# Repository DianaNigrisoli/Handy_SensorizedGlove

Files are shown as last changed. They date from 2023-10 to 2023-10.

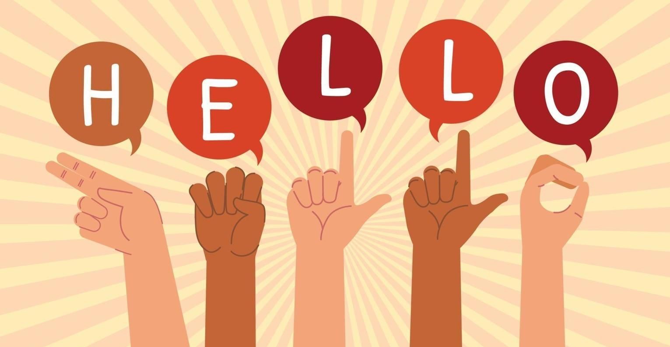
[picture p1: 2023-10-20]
Software/01_Graphics/Download Hello Hand Sign Language Concept for free.jpeg

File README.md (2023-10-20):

# Handy_SensorizedGlove
A wireless sensorized glove for ASL fingerspelling gesture recognition. 
### Course
Electronic Technologies and Biosensor Laboratories

### Developers 
- Arianna De Vecchi <br> arianna.devecchi@mail.polimi.it
- Ilaria Crupi <br> ilaria.crupi@mail.polimi.it
- Diana Nigrisoli <br> diana.nigrisoli@mail.polimi.it

### Setup
* In the command prompt execute:
    ```console
    git clone https://github.com/DianaNigrisoli/Handy_SensorizedGlove.git
    
### Development 
You can find all the scripts and designs in the following folders: 
* Hardware: EAGLE design of the PCB
* Firmware: PSoC Creator code
* Software: Python software for GUI development and Machine Learning classification 
* Box_Solidworks: SOLIDWORKS Part Document of the 3D printed box

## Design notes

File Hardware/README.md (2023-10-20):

# Hardware

## Contents 
In "Project_04" folder: 

| File | Description |
|---|---|
| `Project_04_Schematic.sch` | Schematic |
| `Project_04_Board.brd` | Board |
| `Project_04_ToPrint.pdf` | PCB Design PDF file 1:1 scaled |
| `sparkfun.dru` | Design rules | 
| `README.md` | This README file. |

## Tools 

Both Schematic and Board Design were implemented using the 9.6.2 version of EAGLE software. 

## Detailed files description 
### Schematic 
#### List of schematic components 
| Name | Description | On PCB |
| --- | --- | --- |
| J1 | Plated through-hole 7 pin connector | Generic 0.1 inch spaced male headers connected to flex sensors and force-sensing resistors |
| J2 | Plated through-hole 7 pin connector | Generic 0.1 inch spaced male headers connected to 3.3V supply voltage | 
| J3.1 - PSOC | Plated through-hole 7 pin connector | Generic 0.1 inch spaced female headers connected to PSOC pins from 0.0 to 0.7 |
| J3.2 - PSOC | Plated through-hole 2 pin connector | Generic 0.1 inch spaced female headers connected to PSOC pins 12.0 (SCL) and 12.1 (SDA) |
| J3.3 - PSOC | Plated through-hole 4 pin connector | Generic 0.1 inch spaced female headers connected to PSOC pins 12.6 (RX), 12.7 (TX), 2.7 and 2.6 |
| J3.4 - PSOC | Plated through-hole 2 pin connector | Generic 0.1 inch spaced female headers connected to PSOC pins VDDIO and GND |
| J3 - LED | Plated through-hole 2 pin connector | Generic 0.1 inch spaced male headers connected to yellow LED |
| J4 - BATTERY | Plated through-hole 2 pin connector | Generic 0.1 inch spaced female headers connected to 4.5V external battery and external switch |
| J5 - BT | Plated through-hole 6 pin connector | Generic 0.1 inch spaced male headers connected to HC-05 Bluetooth module |
| J6 - ACC | Plated through-hole 6 pin connector | Generic 0.1 inch spaced male headers connected to LIS3DH Accelerometer |
| J7 - LDO | Plated through-hole 3 pin connector | Generic 0.1 inch spaced male headers connected to 3.3V voltage regulator |

### Board Design
55.88mm x 73.66 mm single layer board design according to the design rules in the sparkfun.dru file.

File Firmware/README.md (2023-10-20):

# Firmware

In **Firmware** folder:

| File | Description |
| ---- | --- |
| LTEBS_Project04 | PSoC Creator folder |
| README.md | This readme file |

In **LTEBS_Project04** folder:

| File | Description |
| ---- | --- |
| LTEBS_Project04.cywrk | PSoC Creator workspace |
| Breadboard_Test02 | PSoC Creator Project |

## Detailed Files Description
A more in-depth description of the **TopDesign** folder is given, together with a decscription of the .c and .h files

### TopDesign
Elements that were connected to the PSoC:
- **Battery_LDO**: 4.5V battery paired with a voltage regulator with output of 3.3V, used to power up the PSoC.
- **I2C**: I2C communication component to read the accelerometer data, connected to pins 12.0 (SDA: data) and 12.1 (SCL: clock). Standard I2C mode is used.
- **UART**: USART communication component to receive (pin 12.6) and transmit (pin 12.7) data through Bluetooth. Baudrate is set at 9600 bps and in interrupt service routine (isr_RX) is connected to the rx_interrupt pin.
- **VFD** and **Pin_BatteryStatus_LED**: the voltage fault detector is set in order to check the value of the 4.5V battery used to power up the system and connected to pin 2.6. When this voltage goes below an undervoltage threshold of 3.6V, the pin "pgood1" is set to 0 and, through a "not" port, a LED connected to the pin 2.7 is turned on.
- **Timer**: timer set to a frequency of 10 Hz with an interrupt service routine (isr_Timer), executed each 100ms.
- **AMux** and **ADC**: seven resistive sensors are connected through a voltage divider to pins going from 0.0 to 0.7 and are then set as inputs to an analog multiplexer. The AMux component is set in order to have 7 inputs, while the Delta-Sigma ADC is set with a 16-bit resolution and in multi-sample mode.
- **Pin_LED_ONBOARD**: pin used for debugging purposes, in order to check that the system has been turned on.

### I2C_Interface.c, I2C_Interface.h, ErrorCodes.h
These files were used in order to achieve communication with the accelerometer via I2C: the functions use "if" statements in order to check that the communication is happening properly and, in case this is not true, they have an error code as output.

### InterruptRoutines.h, InterruptRoutines.c, main.c
Thes first file is used in order to define some global variables; the other two files contain the code that has to run when the device is turned on and the one that has to run when an interrupt occurs, both for the Timer and for the UART elements.
In particular, the code works as described in the next steps:
- At start up, the interrupts, the VFD, the AMux, the ADC and the I2C are initialized. Moreover, the accelerometer is initialized as well, in order to enable the BDU option and to have all three axis running at 25 Hz.
- The system then waits for a UART interrupt: in case this happens and the character read by the system is correct, the code makes the Timer start running.
- Every 100 ms, an interrupt from the Timer occurs, which will first run for 10 times. In this interrupt, each of the AMux inputs is read in a subsequent way via the ADC: the values are checked, eventually corrected if they appear to be out of boundary and each value is summed to the previous one. The same is done for the accelerometer values: they are acquired via the I2C, they are checked and incrementally summed.
- After 10 runs, the interrupt stops the Timer, computes the mean for each of the values that were read from the ADC and from the I2C and creates a string containing these 10 values, separated by a comma. A flag is raised.
- The main.c while(1) loop continuously checks for the flag value: when the flag is raised, the string containing the values is sent via UART and is then lowered.

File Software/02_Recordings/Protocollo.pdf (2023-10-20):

### Protocollo

1. Mano completamente aperta con dorso verso il soggetto
2. Mano completamente chiusa con pressione pollice
3. Mano completamente aperta con palmo verso l’alto
4. A – pollice non premuto
5. B – pollice non premuto
6. C – pollice verso il soggetto
7. D – pollice premuto
8. E – pollice non premuto
9. F – pollice premuto
10. G – pollice premuto, dorso verso il soggetto
11. H – pollice premuto, dorso verso il soggetto
12. I – pollice premuto
13. J – pollice non premuto
14. K – pollice premuto
15. L – dorso verso il soggetto
16. M – pollice non premuto
17. N – pollice non premuto
18. O – pollice premuto
19. P – pollice premuto, dita piegate verso il soggetto
20. Q – dita piegate verso il soggetto
21. R – pollice premuto
22. S – pollice premuto
23. T – palmo verso il soggetto
24. U – pollice premuto
25. V – pollice premuto
26. W – pollice premuto
27. X – pollice premuto
28. Y – dorso verso il soggetto
29. Z – pollice premuto, mano inclinata verso il soggetto

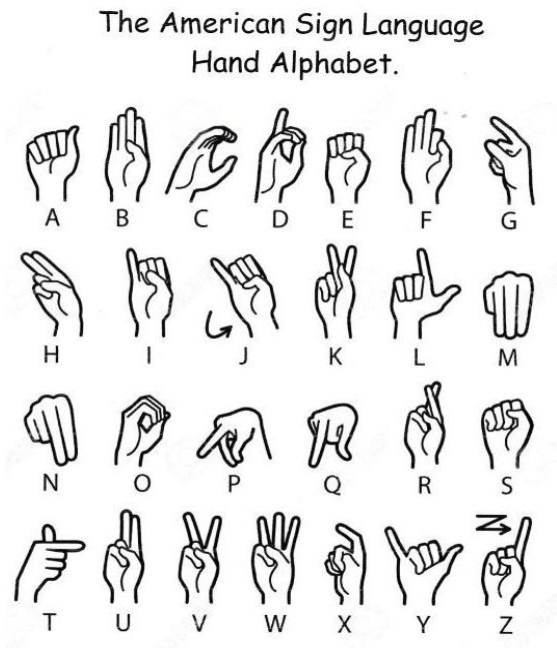
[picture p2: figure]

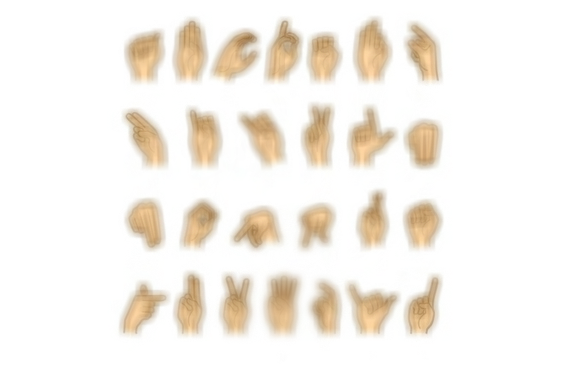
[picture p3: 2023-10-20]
Software/01_Graphics/BlurredASL.png

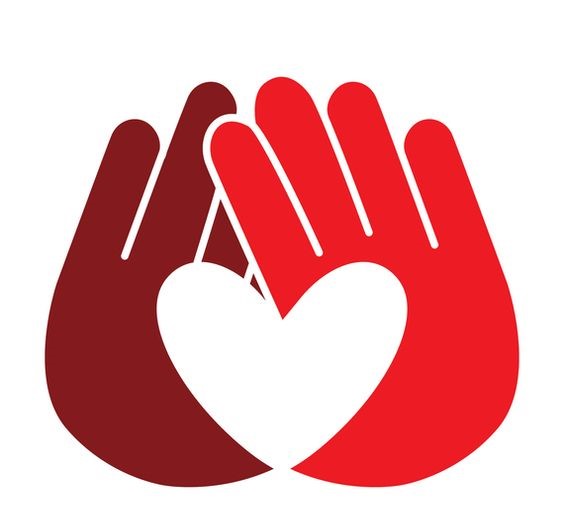
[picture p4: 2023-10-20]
Software/01_Graphics/hearthands2.jpg

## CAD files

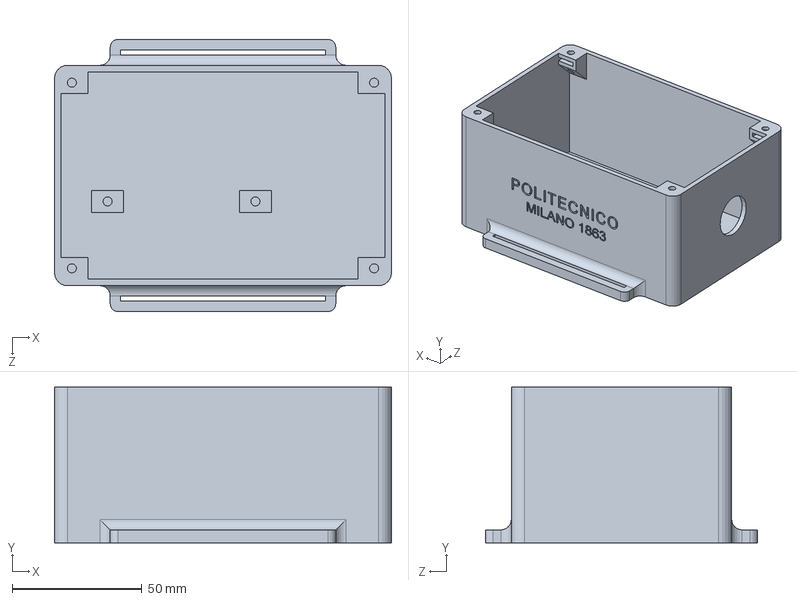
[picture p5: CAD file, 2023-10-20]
Box_Solidworks/Box_3D.SLDPRT
130.0 x 60.0 x 105.0 mm

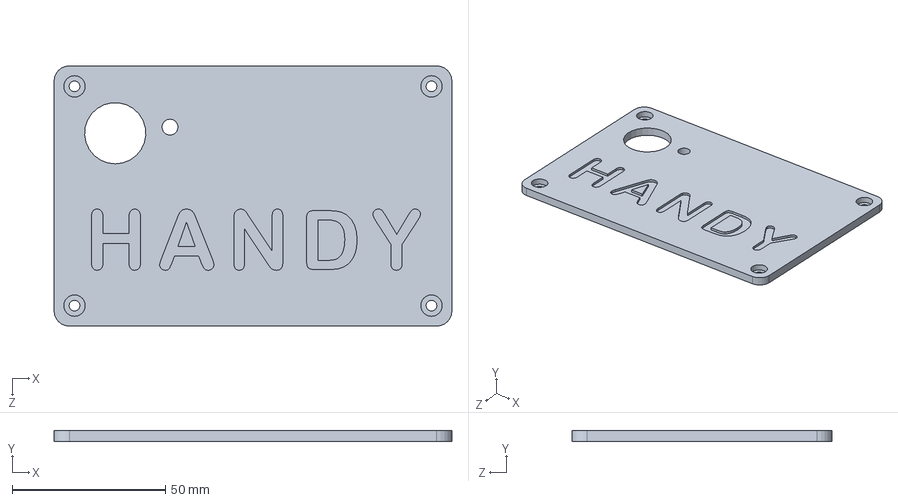
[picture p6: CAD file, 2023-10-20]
Box_Solidworks/Coperchio_Box_3D.SLDPRT
130.0 x 3.50 x 85.0 mm

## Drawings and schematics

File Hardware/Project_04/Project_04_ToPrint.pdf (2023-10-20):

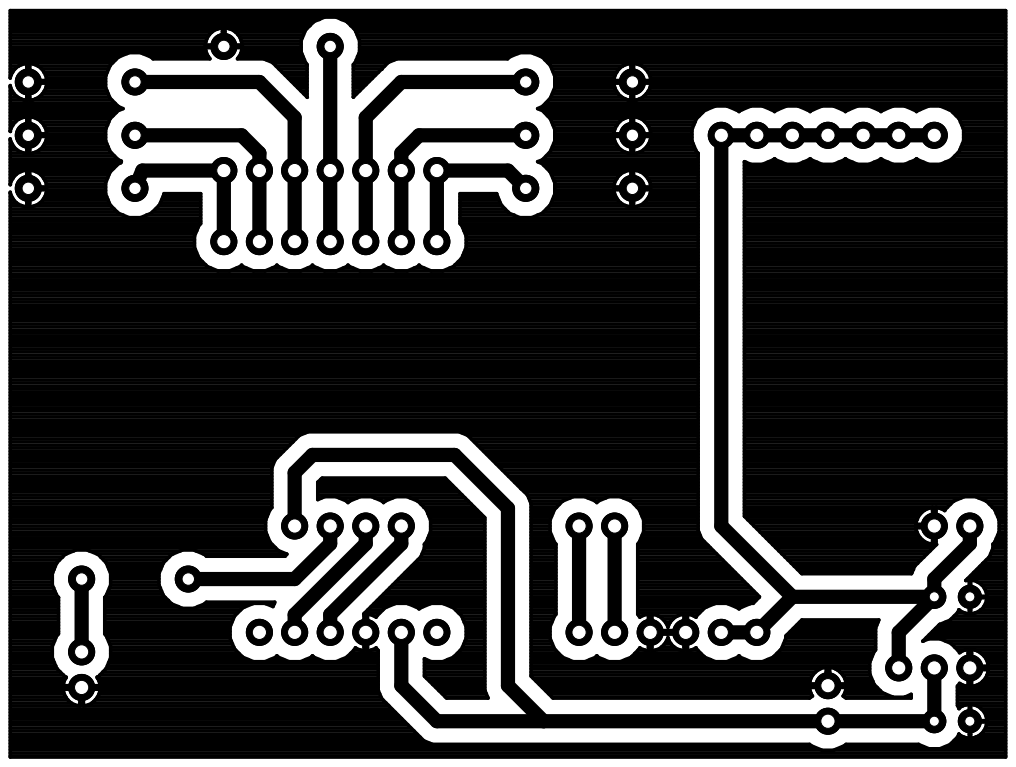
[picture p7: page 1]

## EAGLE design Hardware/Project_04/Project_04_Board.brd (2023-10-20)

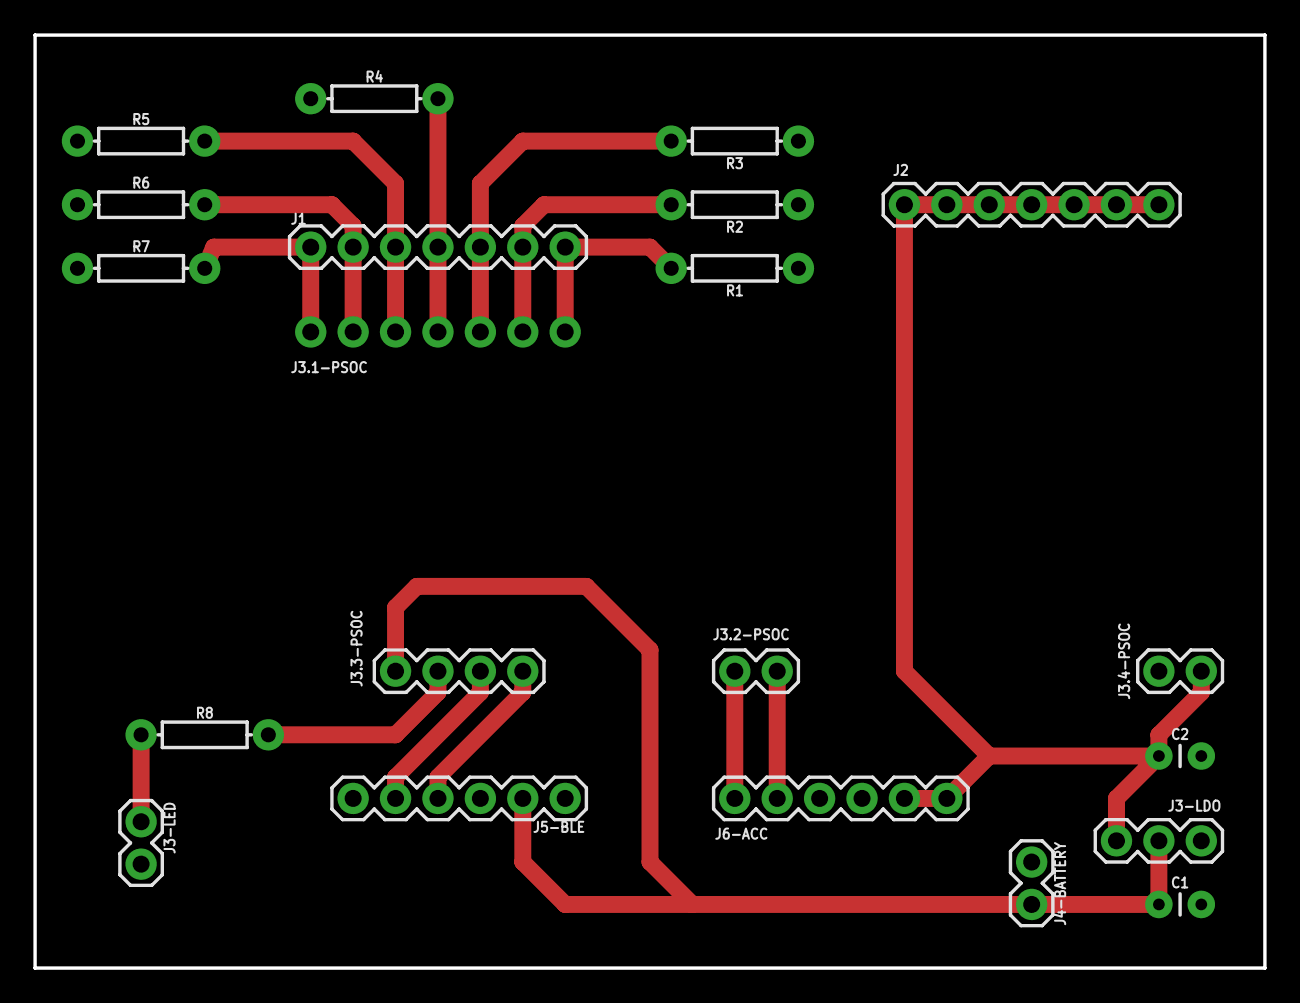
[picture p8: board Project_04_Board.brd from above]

Board: 2 copper layers, 73.7 x 55.9 mm, 21 parts (1 on the bottom side), 15 nets.

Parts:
C1, C2: 1uF; CAP-PTH-2.54
J1, J2, J3.1-PSOC: 1X07
J3-LDO: 1X03
J3-LED, J3.2-PSOC, J3.4-PSOC, J4-BATTERY: 1X02
J3.3-PSOC: 1X04
J5-BLE, J6-ACC: 1X06
R1, R2, R3, R4, R5: 27K; AXIAL-0.3
R6, R7: 10K; AXIAL-0.3
R8: 330; AXIAL-0.3

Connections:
3.3V: C2.1, J2.1, J2.2, J2.3, J2.4, J2.5, J2.6, J2.7, J3-LDO.3, J3.4-PSOC.2, J6-ACC.5, J6-ACC.6
4.5V: C1.1, J3-LDO.2, J3.3-PSOC.1, J4-BATTERY.2, J5-BLE.2
GND: C1.2, C2.2, J3-LDO.1, J3-LED.2, J3.4-PSOC.1, J4-BATTERY.1, J5-BLE.3, J6-ACC.3, J6-ACC.4, R1.P$1, R2.P$1, R3.P$1, R4.P$1, R5.P$1, R6.P$1, R7.P$1
R1: J1.7, J3.1-PSOC.1, R1.P$2
R2: J1.6, J3.1-PSOC.2, R2.P$2
R3: J1.5, J3.1-PSOC.3, R3.P$2
R4: J1.4, J3.1-PSOC.4, R4.P$2
R5: J1.3, J3.1-PSOC.5, R5.P$2
R6: J1.2, J3.1-PSOC.6, R6.P$2
R7: J1.1, J3.1-PSOC.7, R7.P$2
RLED: J3-LED.1, J3.3-PSOC.2, R8.P$1, R8.P$2
RX: J3.3-PSOC.3, J5-BLE.5
SCL: J3.2-PSOC.2, J6-ACC.2
SDA: J3.2-PSOC.1, J6-ACC.1
TX: J3.3-PSOC.4, J5-BLE.4

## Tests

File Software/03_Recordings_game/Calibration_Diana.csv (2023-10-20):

36959 | 34791 | 37827 | 37268 | 32686 | 0 | 0 | 1222 | -3564 | -15283 | open
22683 | 18943 | 25550 | 22003 | 27735 | 39739 | 57388 | -2592 | -620 | -15436 | closed

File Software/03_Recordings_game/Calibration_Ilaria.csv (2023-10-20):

36838 | 34695 | 39081 | 22336 | 33493 | 0 | 0 | -2099 | -9715 | -12051 | open
21969 | 19050 | 25655 | 13078 | 22476 | 0 | 56936 | -300 | -8448 | -13068 | closed

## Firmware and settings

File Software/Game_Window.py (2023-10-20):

###########
# IMPORTS #
###########

import struct
import sys
import time
from datetime import datetime
import logging
import random
import csv
import pandas as pd

from PyQt5 import QtCore
from PyQt5.uic import loadUi
from PyQt5.QtGui import QPixmap

from PyQt5.QtCore import (
    QObject,
    QThreadPool,
    QRunnable,
    pyqtSignal,
    pyqtSlot, 
    QTimer,
    Qt,
)
from PyQt5.QtGui import QCursor

from PyQt5.QtWidgets import (
    QApplication,
    QMainWindow,
    QPushButton,
    QComboBox,
    QHBoxLayout,
    QGridLayout,
    QVBoxLayout,
    QWidget, QLabel,
    QTextEdit,
    QMessageBox,
    QLineEdit,
    QDialog,
   
     
)
import serial
import serial.tools.list_ports
import csv
import os
import globals
from SerialWorker_connection import SerialWorker, SerialWorkerSignals
#from Menu_Window import MenuWindow
import ResourceFiles
from ML_manager import MLPredictor
from Calibration_Window import CalibrationWindow

# Logging config
logging.basicConfig(format="%(message)s", level=logging.INFO)

#Globals 
COUNTDOWN_SECS=10
CALIBRATING= False

###############
# GAME WINDOW #
###############

class PlayWindow(QWidget): 
    
    def __init__(self):
        super().__init__()
        
        loadUi('01_Graphics/Game_Window.ui', self)
       
        #Settings for buttons and labels
        self.Username_label.setText(globals.UserName) 
        self.start_button.clicked.connect(self.handle_start_button)
        self.timer = QTimer(self)
        self.timer.timeout.connect(self.update_countdown)
        self.solution_button.clicked.connect(self.show_solution) 
        self.start_button_pressed = False
        

        self.solution_button.setEnabled(False)
        self.exit_btn.clicked.connect(self.BackToMenu)

        self.calibration_btn.clicked.connect(self.calibration_start)

        self.image_label.setScaledContents(True)
        
        self.greatjob_label.setHidden(True)
        self.tryagain_label.setHidden(True)
        self.StayStill_label.setHidden(True)

        #Cursor 

        QApplication.restoreOverrideCursor()

        #Countdown 
        self.countdown_seconds = COUNTDOWN_SECS 
        self.update_countdown()

        #Score
        self.score =0 
        self.score_value.setText("0")

    
        #Machine learning classifier init 
        model_path = 'RandomForest_model.sav'
        scaler_path = 'scaler_acc.sav'
        self.model = MLPredictor(model_path, scaler_path)      

        
    def handle_start_button(self):
        """!
        @brief this function controls whether 
        the start button has been pressed for the first time or not (different management of the timer)
        and triggers the function self.start_game_clicked()
        """
        
        if self.check_calibration() == 0: 
            return

        self.classified_target.setText("?")
        self.solution_button.setEnabled(False)
        self.image_label.clear()
        self.image_label.hide()

        if not self.start_button_pressed:
            self.timer.start(1000)
            self.start_game_clicked()
            self.start_button_pressed = True
            self.start_button.setEnabled(False)
            self.calibration_btn.setEnabled(False)
        else:
            self.restart_timer()
            self.start_game_clicked()
            self.start_button.setEnabled(False)
            self.calibration_btn.setEnabled(False)


    def update_countdown(self):
        """!
        @brief this function updates the countdown 
            and manages the communication with the serial worker for starting the recording  
        """
        self.countdown_label.setText(str(self.countdown_seconds-1))
        self.countdown_seconds -= 1

        if (self.countdown_seconds) < 0:
            #the timer has expired, we expect for some data from the serial worker 
            self.timer.stop()
            self.countdown_label.setText("0")
            self.StayStill_label.setHidden(True)
            
            #we expect to receive some data from serial worker 
            globals.serialData = True
            data = self.receive_data()
            
            self.start_button.setEnabled(True)
            self.calibration_btn.setEnabled(True)

            if data:
                self.prediction = self.model.predict_letter(data, self.open, self.closed)#ML classification of the data
                self.classified_target.setText(self.prediction) 
                self.solution_button.setEnabled(True) #enabling the button for showing solution 
                self.update_csv(data) #update the csv with the new data               
           
        elif (self.countdown_seconds) < 1: 
            #the timer has almost expired -> the recording can start
            self.countdown_label.setText("0")
            self.StayStill_label.setHidden(False)
            #sending the recording signal to the serial worker
            globals.serial_worker.send('s')


    def restart_timer(self):
        """!
        @brief restarts the timer after the time has expired.
        """
        self.timer.stop()
        self.countdown_seconds = COUNTDOWN_SECS
        self.update_countdown()
        self.timer.start(1000)


    def start_game_clicked(self): 
        """!
        @brief this function manages the start of the game.
        """ 
        self.greatjob_label.setHidden(True)
        self.tryagain_label.setHidden(True)
        logging.info("Starting game")
        self.update_letter()


    def update_letter(self):
        """!
        @brief this function updates the letter asked to the player in a randomic way
        """
        self.random_letter = random.choice("ABCDEFGHIJKLMNOPQRSTUVWXYZ")
        self.letter_target.setText(self.random_letter)
    

    def receive_data(self):
        """!
        @brief in a while loop controls if some data has been received.
        """
        #time checking for avoiding an infinite loop
        start_time = time.time()
        elapsed_time=0

        while globals.serialData:  
            
            current_time = time.time()
            elapsed_time = current_time - start_time

            info = globals.serial_worker.receive()

            #A string of data has been received 
            if globals.READING:
                logging.info("Data: {}.".format(info))
                list_means = info.split(",")
                globals.serialData = False
                globals.READING = False
                return list_means
            
            #No string has been received in EXP_READ_TIME seconds 
            elif elapsed_time>=globals.EXP_READ_TIME: 
                logging.info("Time expired, no message arrived")
                globals.serialData = False
                globals.READING = False
                return 


    def show_solution(self): 
        """!
        @brief this function allows the player to see what was the right gesture.
        """
        image_path = "hand_images\\"+ self.random_letter+".png"
        pixmap = QPixmap(image_path)
        self.image_label.setPixmap(pixmap)
        self.image_label.show()



    def update_csv(self, data): 
        """!
        @brief updates the csv with the new sensors values, the date, the performance of the player (asked letter and classified letter)
        """
        filename = globals.UserName + '.csv'     
        data.append(self.random_letter)
        data.append(self.classified_target.text()) #append per la lettera classificata dal modello
        
        if(self.random_letter == self.classified_target.text()): 
            data.append(1)
            self.greatjob_label.setHidden(False)
            self.score += 1
            self.score_value.setText(str(self.score))
        else:
            data.append(0)
            self.tryagain_label.setHidden(False)
            self.score_value.setText(str(self.score))

        now = datetime.now() 
        date = now.strftime("%d_%m_%Y")
        data.append(date)

        with open('03_Recordings_game/'+ filename, 'a',newline='') as csv_file:
            writer = csv.writer(csv_file)
            writer.writerow(data)
    

    def check_calibration(self): 
        """!
        @brief checks whether the user as already done a calibration (at least once).
        """
        folder_path='03_Recordings_game'
        count=0
        for filename in os.listdir(folder_path):
            if filename == 'Calibration_' + globals.UserName + '.csv':
              count += 1
        
        if count == 0: 
            
            msgBox = QMessageBox()
            msgBox.setIcon(QMessageBox.Warning)
            msgBox.setText("Please, click on calibration button before starting the game")
            msgBox.setWindowTitle("Missing Calibration")
            msgBox.setStyleSheet("background-color: rgb(255, 221, 188)")
            msgBox.exec()
            return 0
        
        else: 
            
            with open(folder_path + '/Calibration_' + globals.UserName + '.csv', newline='') as f:  
                
                csv_reader = csv.reader(f)

                self.open  = next(csv_reader)[:-4]
                self.open=[float(i) for i in self.open]
                logging.info("Open: {}".format(self.open))

                self.closed = next(csv_reader)[:-4]
                self.closed=[float(i) for i in self.closed]
                logging.info("Closed: {}".format(self.closed))

                return 1

    def calibration_start(self): 
        """!
        @brief the function opens another winowo for calibration.
        """
        self.calibration_window = CalibrationWindow()
        self.calibration_window.show()

    def ExitHandler(self):
        """!
        @brief Kill serial worker.
        """
        globals.serialData = False
        globals.KILL = True
        globals.serial_worker.killed()



    def BackToMenu(self):
        """!
        @brief allows to go back to menu.
        """
        self.ExitHandler()
        self.close()
        
    
    

if __name__ == "__main__":
    globals.UserName='Diana'
    app = QApplication(sys.argv)
    window = PlayWindow()
    window.show()
    sys.exit(app.exec_())

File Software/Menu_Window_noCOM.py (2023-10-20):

###########
# IMPORTS #
###########

import struct
import sys
import time
from datetime import datetime
import logging
from PyQt5 import QtCore
from PyQt5.uic import loadUi
from PyQt5.QtCore import (
    QObject,
    QThreadPool,
    QRunnable,
    pyqtSignal,
    pyqtSlot,
    Qt,
)
from PyQt5.QtGui import QCursor

from PyQt5.QtWidgets import (
    QApplication,
    QMainWindow,
    QPushButton,
    QComboBox,
    QHBoxLayout,
    QGridLayout,
    QVBoxLayout,
    QWidget, QLabel,
    QTextEdit,
    QMessageBox,
    QLineEdit,
    QDialog,
)
import serial
import serial.tools.list_ports
import csv
import globals
from SerialWorker_connection import SerialWorker, SerialWorkerSignals
from Game_Window import PlayWindow
from Statistics_Window import StatsWindow
import ResourceFiles

# Logging config
logging.basicConfig(format="%(message)s", level=logging.INFO)


class MenuWindow(QWidget): 
    
    def __init__(self):
        super().__init__()
        
        #Initialize the serial worker 
        globals.serial_worker = SerialWorker(None)

        self.no_port_found = True

        #Load of user interface (done with Qt Designer)
        loadUi('01_Graphics/Menu_Window.ui', self)
       
        #CONNECTIONS OF BUTTONS WITH WETHODS
        #Statistics & Play 
        self.statistics_button.clicked.connect(self.statistics_clicked)
        self.play_button.clicked.connect(self.play_clicked)
        self.log_out_btn.clicked.connect(self.back_to_log_in)
        '''
        #Selection and connection to port 
        self.com_list_widget.currentTextChanged.connect(self.port_changed)
        self.conn_btn.setCheckable(True)
        self.conn_btn.clicked.connect(self.on_toggle)

        serial_ports = [
            p.name
            for p in serial.tools.list_ports.comports()
        ]
        self.com_list_widget.addItems(serial_ports)'''
        
       

    ###############################
    # SERIAL SIGNALS - CONNECTION #
    ###############################
    def port_changed(self):
        """!
        @brief Update conn_btn label based on selected port.
        """
        self.port_text = self.com_list_widget.currentText()
        self.conn_btn.setText("Connect to port {}".format(self.port_text))


   
    def start_serialWorker(self, port_name):
        """!
        @brief Allow connection and disconnection from selected serial port.
        """
        
        logging.info('set_up worker')
        # setup worker
        globals.serial_worker = SerialWorker(port_name)  # needs to be re defined
        # connect worker signals to functions
        globals.serial_worker.signals.status.connect(self.check_serialport_status)
        globals.serial_worker.signals.device_port.connect(self.connected_device)
        # execute the worker

        #if (not self.no_port_found): 
        self.threadpool.start(globals.serial_worker)
        
        #else: 
        #    globals.serial_worker.run

       
        

    def check_serialport_status(self, port_name, status):
        """!
        @brief Handle the status of the serial port connection.

        Available status:
            - 0  --> Error during opening of serial port
            - 1  --> Serial port opened correctly
        """
        if status == 0:
            #self.conn_btn.setChecked(False)
             logging.info("NOT connected to port {}".format(port_name))
        elif status == 1:
            # enable all the widgets on the interface
            '''
            self.com_list_widget.setDisabled(True)  # disable the possibility to change COM port when already connected
            self.conn_btn.setText(
                "Disconnect from port {}".format(port_name)
            ) '''
            logging.info("Connected to port {}".format(port_name))


    def connected_device(self, port_name):
        """!
        @brief Checks on the termination of the serial worker.
        """
        logging.info("Port {} closed.".format(port_name))


    def ExitHandler(self):
        """!
        @brief Kill every possible running thread upon exiting application.
        """
        globals.serialData = False
        globals.KILL = True
        globals.serial_worker.killed()


    def find_com(self): 
        """!
        @brief tries to connect to all the available COM and returns the one belonging to the Glove
        """
        serial_ports = [
            p.name
            for p in serial.tools.list_ports.comports()
        ]
        

        self.no_port_found = True
        i=0
        
        logging.info("serial_ports: {}.".format(serial_ports))

        while(self.no_port_found and i<len(serial_ports)):
            port=serial_ports[i]
            self.start_serialWorker(port)
            time.sleep(5)
            
            if globals.CONN_STATUS: 
                globals.serial_worker.send('s') 
                globals.serialData = True

                if self.receive_data(port): 
                    self.no_port_found = False
                    break
                else: 
                    self.ExitHandler()
                    logging.info("Connected but not received")
                    i=i+1

            #elif (i+1) >= len(serial_ports): 
            #    logging.info("No serial port found")
            #    self.ExitHandler()
            #    break
            else: 
                self.ExitHandler()
                logging.info("Not connected to {}.".format(port))
                #logging.info("globals.CONN_STATUS: {}". format(globals.CONN_STATUS))
                i=i+1
                
        return port 
    

    def receive_data(self, port):
        """!
        @brief in a while loop controls if some data has been received.
        """
        #time checking for avoiding an infinite loop
        start_time = time.time()
        elapsed_time=0

        while globals.serialData:  
            
            current_time = time.time()
            elapsed_time = current_time - start_time

            info = globals.serial_worker.receive()

            #A string of data has been received 
            if globals.READING:
                logging.info("Something received")
                globals.serialData = False
                globals.READING = False
                return True
            
            #No string has been received in EXP_READ_TIME seconds 
            elif elapsed_time>=globals.EXP_READ_TIME: 
                logging.info("Time expired --> wrong COM {}.".format(port))
                globals.serialData = False
                globals.READING = False
                return False
            
    
    ################
    # OPTIONS MENU #
    ################
        
    @pyqtSlot(bool)
    def play_clicked(self):
       """!
        @brief Starts the game window
        """
       QApplication.setOverrideCursor(Qt.WaitCursor)
       #Start threadpool
       self.threadpool = QThreadPool()
       right_port=self.find_com()
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

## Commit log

2023-10-20 upload of final total project
    [Alejandro1_14_06_2023.csv, Alejandro2_14_06_2023.csv, Alessandro1_14_06_2023.csv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]
2023-10-20 small change in power point

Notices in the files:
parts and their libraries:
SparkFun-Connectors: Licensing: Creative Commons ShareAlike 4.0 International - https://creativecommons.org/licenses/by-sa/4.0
